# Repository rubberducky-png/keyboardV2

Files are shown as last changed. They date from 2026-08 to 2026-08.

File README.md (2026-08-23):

# keyboardV2: compact 61-key keyboard

A fully custom 61-key mechanical keyboard designed by me, including the PCB, case, firmware, and assembly.

Funded With The Macondo Program

## Features

- Custom PCB designed from scratch
- Hot-swappable MX-compatible switches
- VIA firmware
- Screw-in stabilizers
- 3D printed two-piece tray mount case
- Switch plate
- PCB foam
- bluetooth
- RGB lights
  
## Why I Built It

I built another keyboard before this and ended up hating how it looked and how I desgined it. So I went back to the drawing board and decided to make one I would actually like.

## Design Process

The project began by selecting a 61-key layout that has a lot of function but is also on the smaller side. I then designed the PCB in KiCad, routed all the traces, and added support for hot-swap sockets and USB-C connectivity. After the electronics were complete I designed a simple tray mount in Onshape. The case is made out of two PLA printed pieces and includes a shelf for the pcb to rest on. Because of small bed size I will have to print them in pieces.

Finally, the keyboard will be flashed with VIA firmware

## Challenges

Some of the biggest challenges included:

- Learning PCB routing and keyboard matrix design
- Designing a printable case that was able to support the pcb well
- Ensuring all mounting points aligned correctly

## Images and Renders!

### Matrix Schematic


### OnShape Render

#### Case


### PCB


### Assembly


## Bill of Materials (BOM)

| # | Component | Qty. | Cost |
|---:|---|---:|---:|
| 1 | Glorious Fox Linear Mechanical Switches | 110 | $24.99 |
| 2 | 1N4148 Diodes | 120 | $5.99 |
| 3 | GATERON PCB Mounted Stabilizer | 1 | $9.10 |
| 4 | SuperMini nRF52840 | 1 | $13.99 |
| 5 | SK6812MINI-E | 100 | $18 |
| 6 | Kalih Hotswap sockets | 100 | $12.50 |
| 7 | JLCPCB PCB Fabrication + shipping | 5 | $24.14 |
| 8 | 3.7V LiPo cell rated ~750mAh | 1 | $8.49 |
| 9 | JST-PH, 2mm pitch connector | 1 | $5.99 |
| 10 | standard SPDT slide switch, 0.1" (2.54mm) pin spacing | 1 | $7.99 |
| 11 | 2 Pin Momentary Tactile Tact Push Button | 1 | $5.99 |
| 12 | Womier Double Shot PBT Keycaps Set Cherry Profile | 1 | $17.99 |
| 13 | 100nF capacitors | 1 | $4.99 |
| 13 | Chip Capacitor MLCC 22uF | 1 | $7.60 |
| | **Total** | | **$167.75** |

## Shoutout hackclub and the macondo program

</center>

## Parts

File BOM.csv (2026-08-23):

SI No. | Name | Notes | Quantity | Price Per Unit | Cost | Total | Link
1 | Glorious Fox Linear Mechanical Switches | MX-compatible linear switches; 110-pack | 110 | 0.2272 | 24.99 |  | https://www.amazon.com/GLORIOUS-Linear-Mechanical-Switches-Keyboards/dp/B0D7QW8SQ9
2 | 1N4148 Diodes | Through-hole switching diodes for keyboard matrix | 120 | 0.0499 | 5.99 |  | https://www.amazon.com/120Pcs-Rectifier-100Volt-Electronic-Silicon/dp/B0DN62QFYS
3 | GATERON PCB Mounted Stabilizer | Set for stabilizing larger keys (spacebar, shift, enter) | 1 | 9.10 | 9.10 |  | https://www.gateron.com/products/gateron-pcb-mounted-stabilizer?VariantsId=10538
4 | SuperMini nRF52840 | Pro Micro alternative BLE dev board, ZMK/Nice!Nano compatible | 1 | 13.99 | 13.99 |  | https://www.amazon.com/AITRIP-Development-Bluetooth-Management-Module%EF%BC%8CNano/dp/B0DCZJKYL1
5 | SK6812MINI-E | Addressable per-key RGB LED, 100-pack | 100 | 0.18 | 18.00 |  | https://www.amazon.com/100PCS-Similar-WS2812B-Individually-Addressable/dp/B0DMNBBM9V
6 | Kailh Hotswap sockets | MX-compatible hotswap sockets, 100-pack | 100 | 0.125 | 12.50 |  | https://www.amazon.com/Hot-swappable-Socket-CPG151101S11-Mechanical-Keyboard/dp/B096WZ6TJ5
7 | JLCPCB PCB Fabrication + shipping | 5 PCBs; manufacturing + shipping from actual quote | 5 | 4.828 | 24.14 |  | https://jlcpcb.com
8 | 3.7V LiPo cell rated ~750mAh | Rechargeable lithium polymer cell w/ JST-PH connector | 1 | 8.49 | 8.49 |  | https://www.amazon.com/YTKavq-Battery-Lithium-Rechargeable-Connector/dp/B08TV4J9H7
9 | JST-PH, 2mm pitch connector | Battery connector; female socket w/ silicone cable | 1 | 5.99 | 5.99 |  | https://www.amazon.com/JST-PH-Connector-Silicone-Cables-Female/dp/B0F9PD2LPW
10 | standard SPDT slide switch, 0.1" (2.54mm) pin spacing | On/off power switch | 1 | 7.99 | 7.99 |  | https://www.amazon.com/SPDT-Mini-Micro-Slide-Switch/dp/B0DN69PJ43
11 | 2 Pin Momentary Tactile Tact Push Button | Reset button | 1 | 5.99 | 5.99 |  | https://www.amazon.com/Momentary-Tactile-Switches-Through-Breadboard/dp/B0G5Q9RPJW
12 | Womier Double Shot PBT Keycaps Set Cherry Profile | Doubleshot PBT keycap set, Cherry profile | 1 | 17.99 | 17.99 |  | https://www.amazon.com/Keycaps-Doubleshot-Percent-Mechanical-Keyboard/dp/B0DDC6PNY6
13 | 22uF 0805 MLCC (CS2012X5R226M250NRE) | Bulk capacitor for LED power line, 0805 SMD, 10-pack | 10 | 0.499 | 4.99 |  | https://www.amazon.com/Chip-Capacitor-MLCC-22uF-CS2012X5R226M250NRE/dp/B096WDCLWY
14 | CHANZON 100nF 0805 SMD Ceramic Capacitor | Decoupling cap, one per LED (61 needed), 100-pack | 100 | 0.076 | 7.60 |  | https://www.amazon.com/CHANZON-100nF-Ceramic-Capacitor-100pcs/dp/B0GWH4RRQS
 |  |  |  |  |  | 167.75

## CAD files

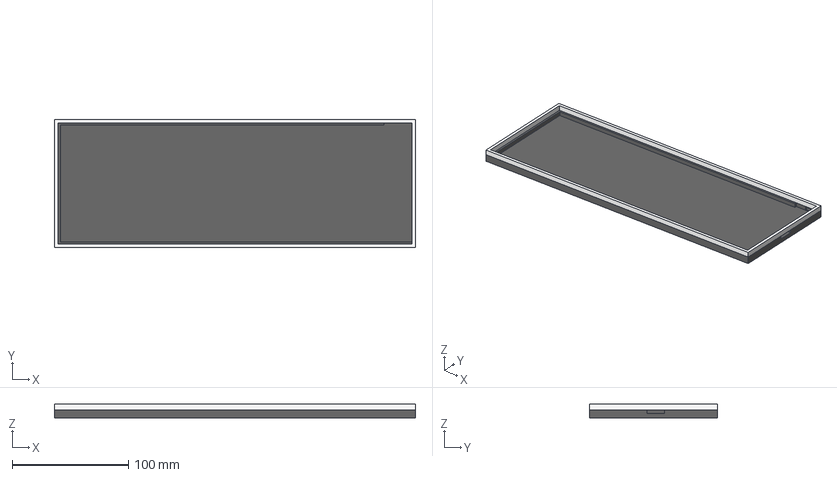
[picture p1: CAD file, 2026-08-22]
CAD/Case.step
310.7 x 110.5 x 12.0 mm

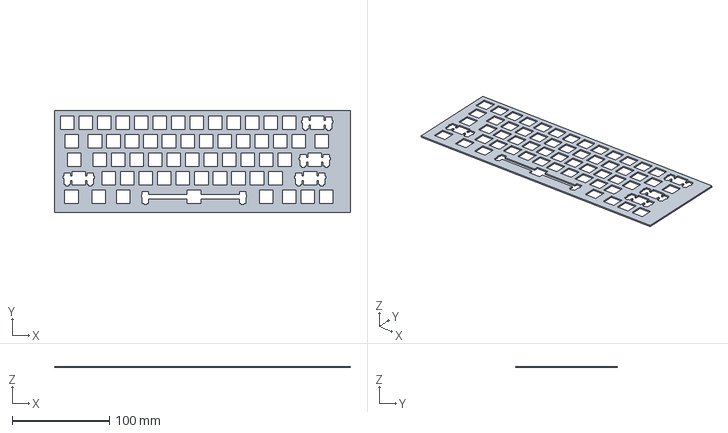
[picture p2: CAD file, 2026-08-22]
CAD/Plate.step
304.5 x 105.1 x 1.50 mm

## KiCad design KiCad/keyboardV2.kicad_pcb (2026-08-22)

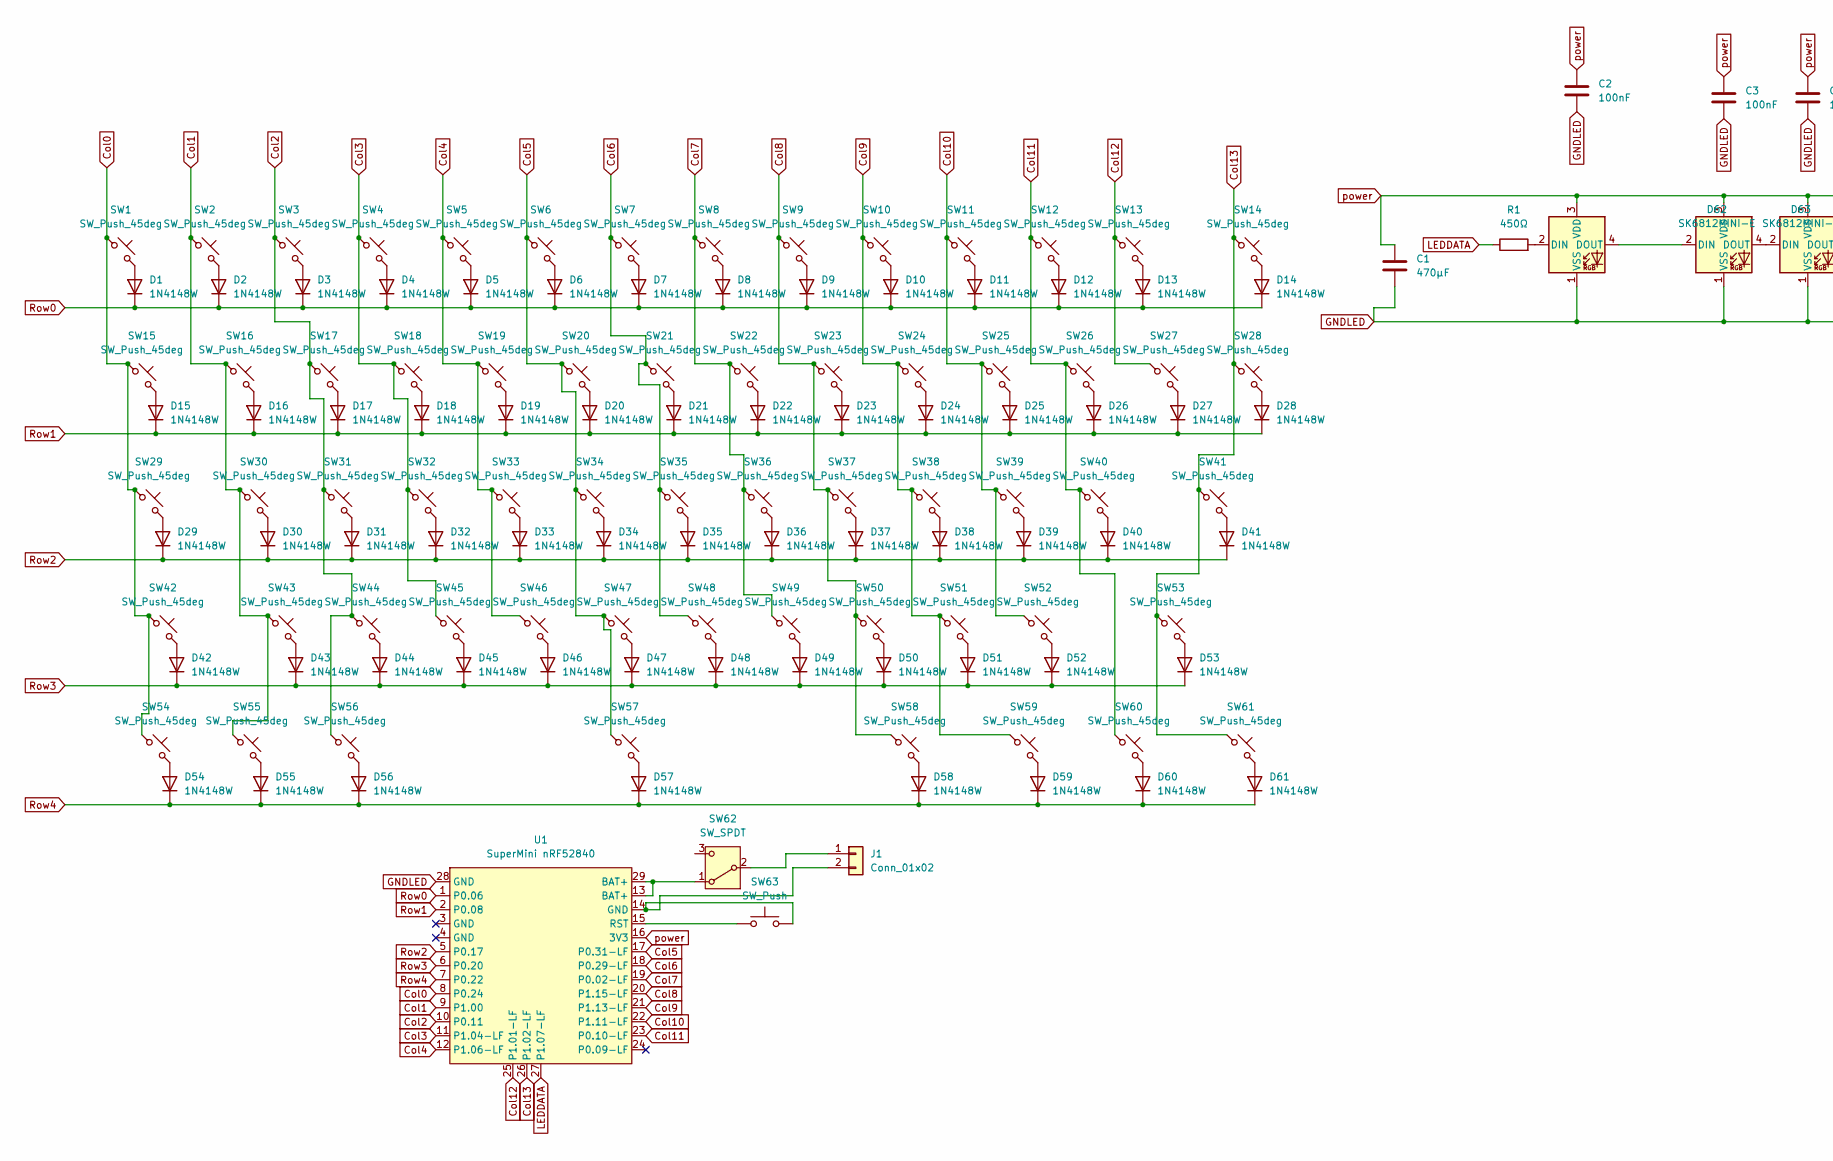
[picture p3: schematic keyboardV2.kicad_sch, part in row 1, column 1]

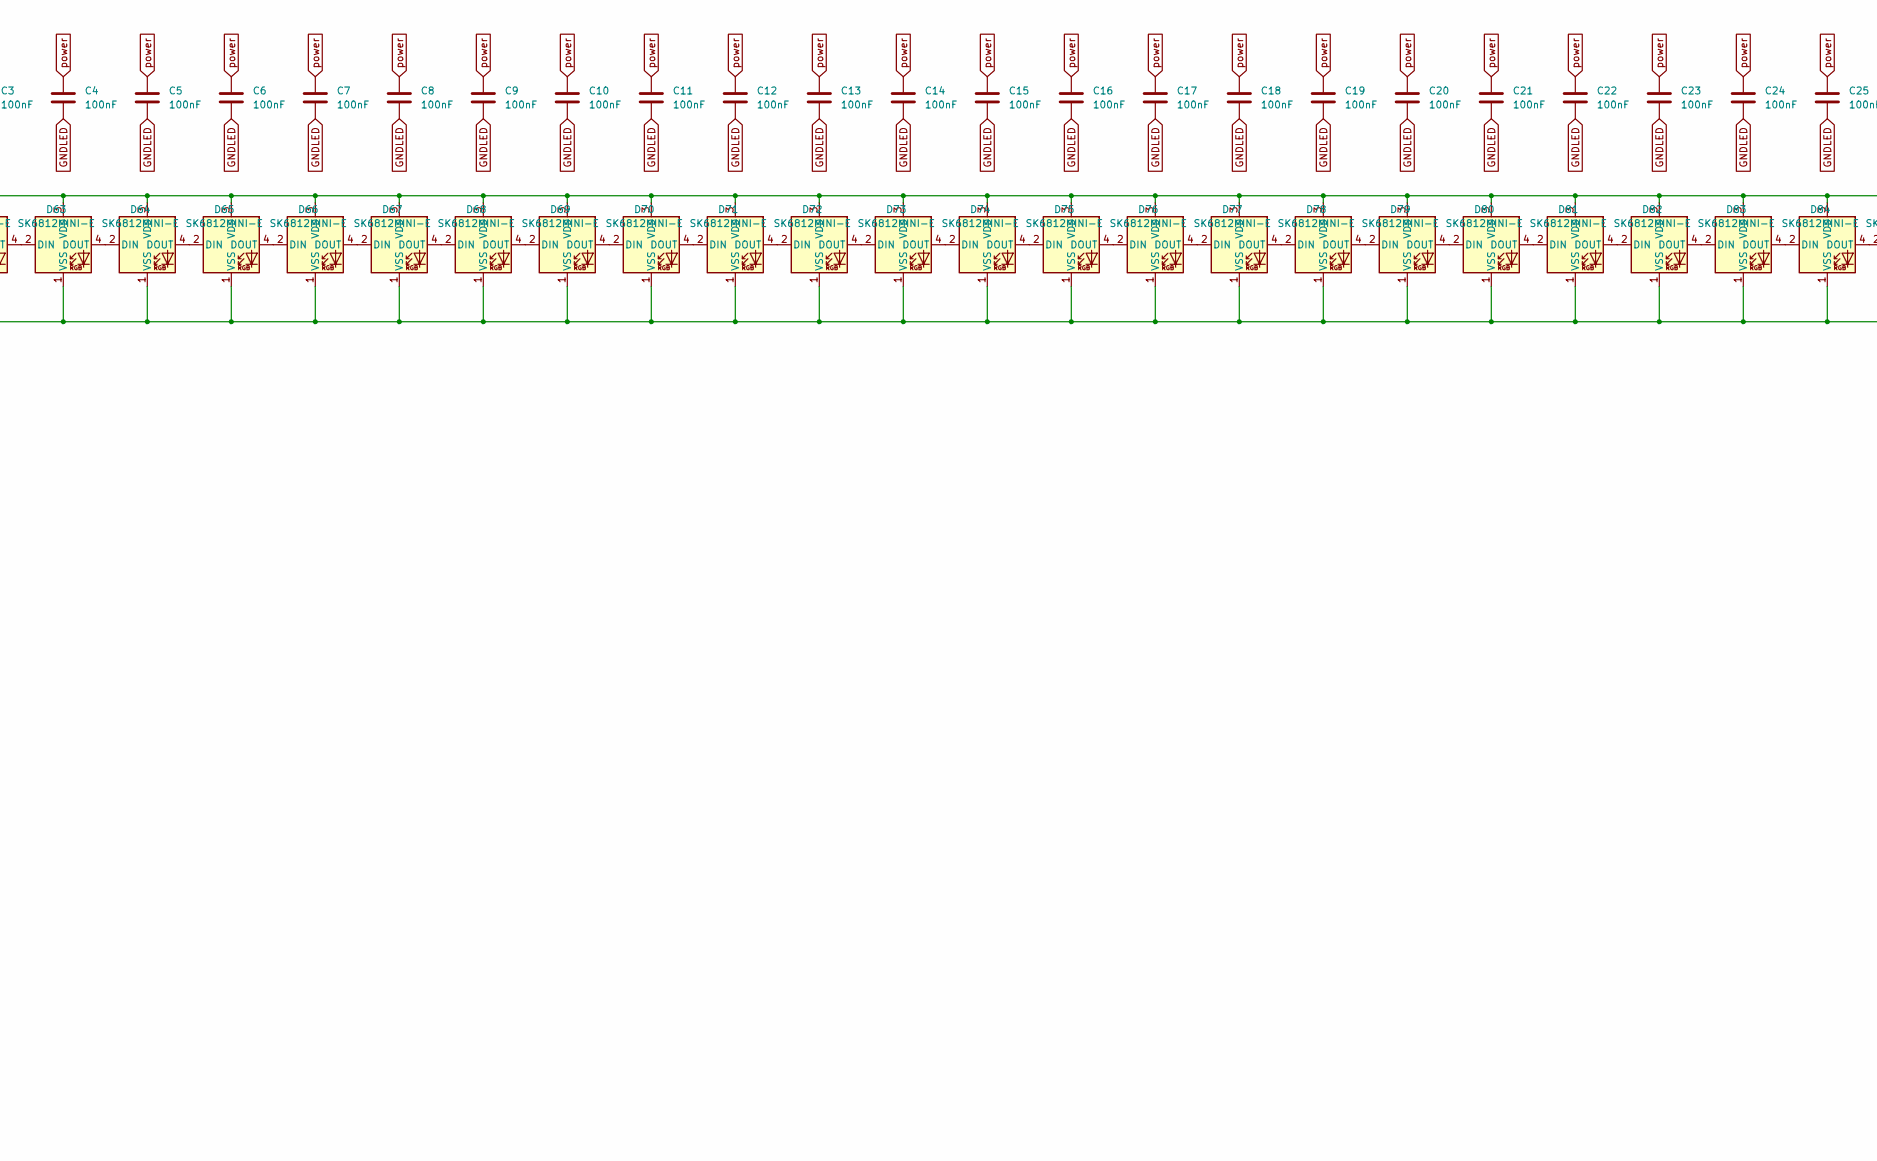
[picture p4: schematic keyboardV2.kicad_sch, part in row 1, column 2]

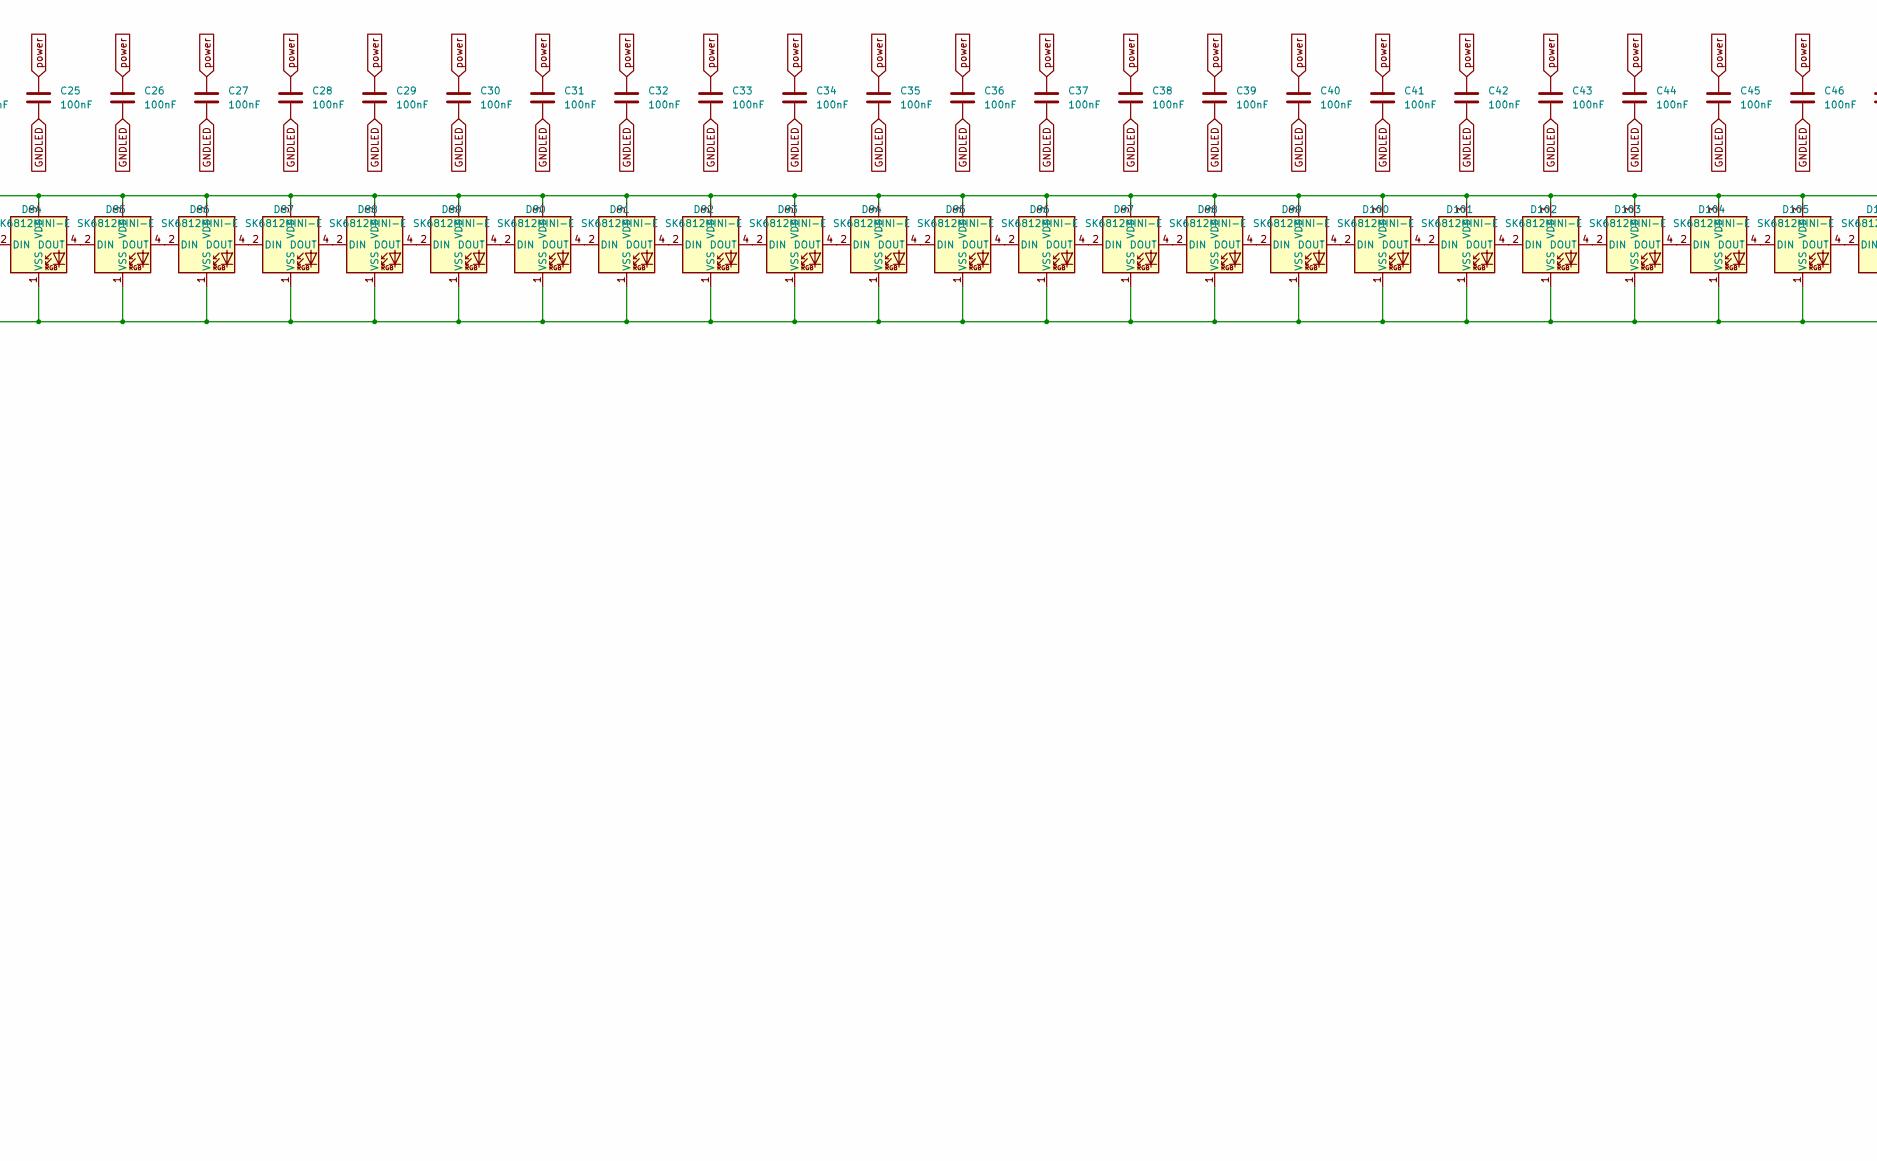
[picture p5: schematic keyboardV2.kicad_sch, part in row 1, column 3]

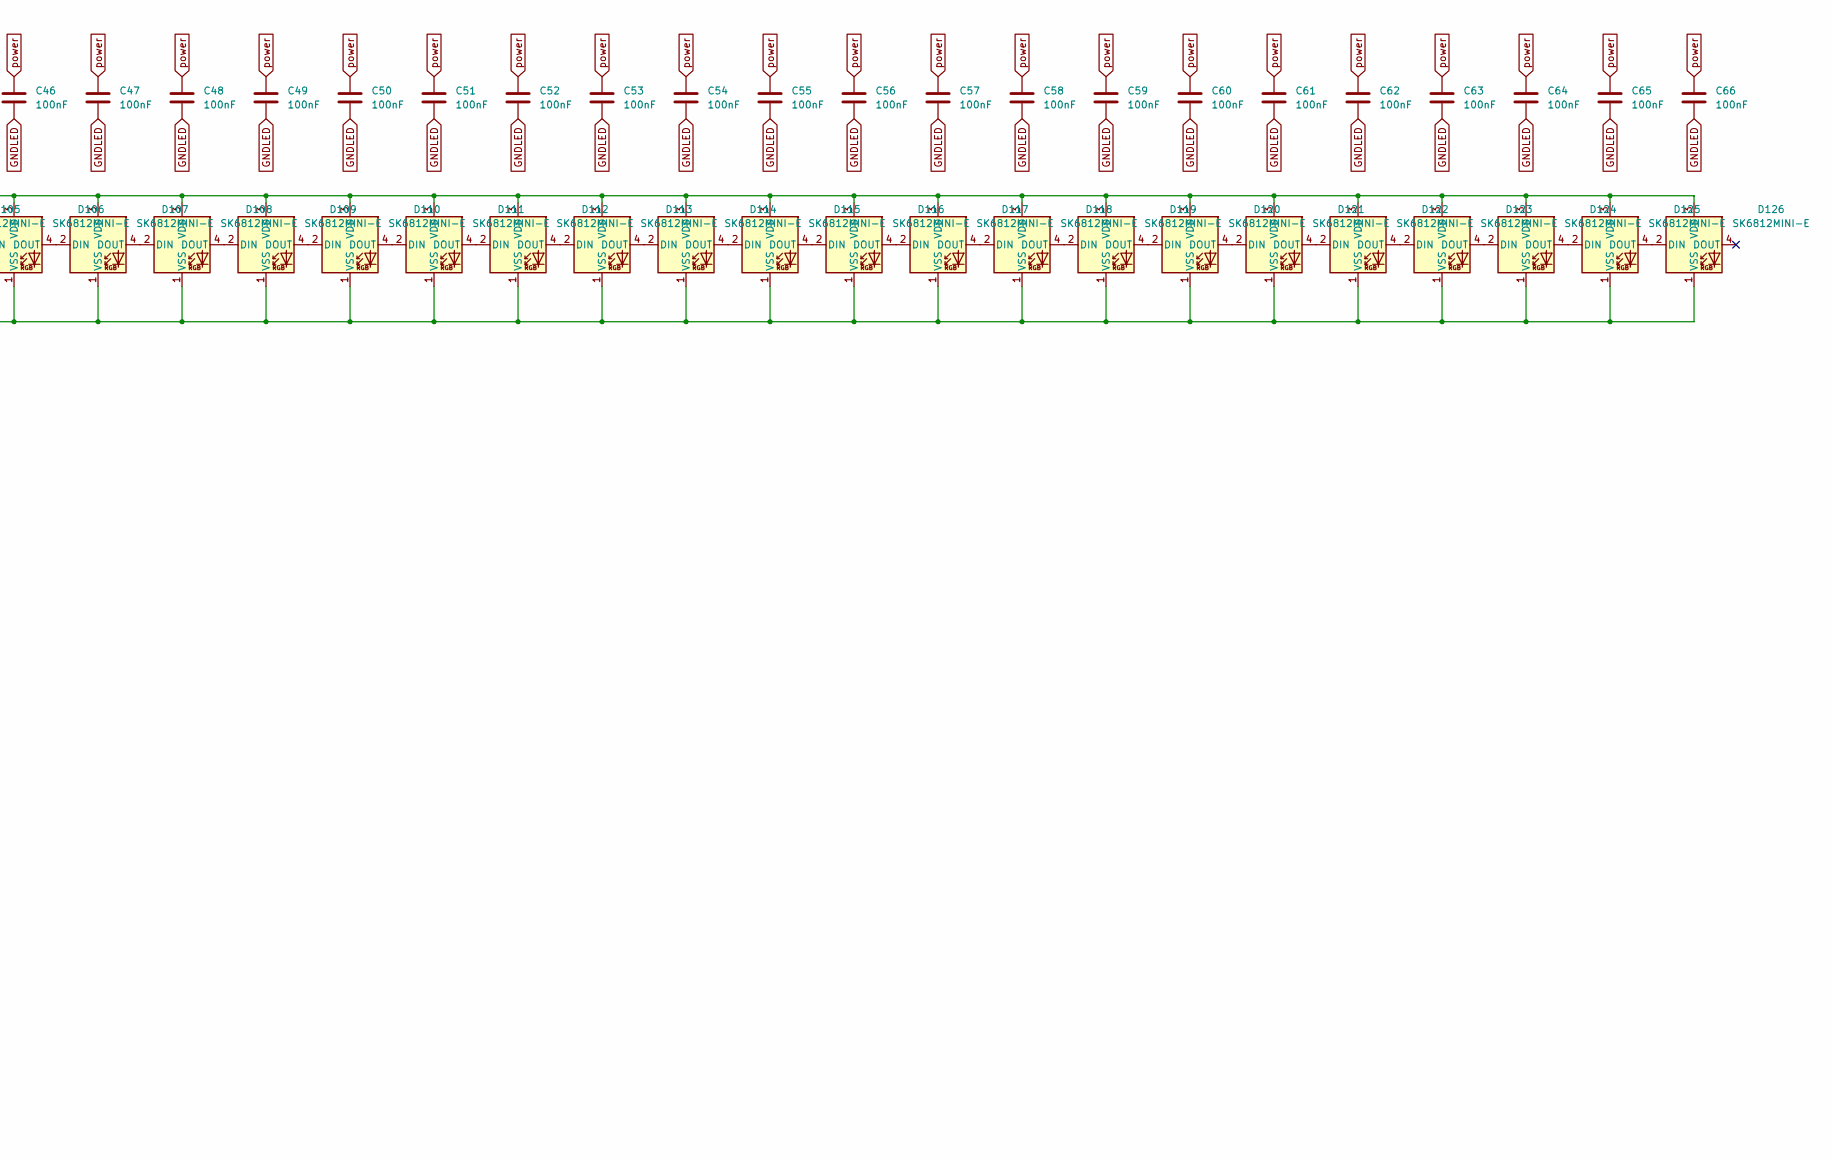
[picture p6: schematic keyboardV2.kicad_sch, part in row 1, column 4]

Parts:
C1: 470µF; C_0805_2012Metric
C2, C3, C4, C5, C6, C7, C8, C9, C10, C11, C12, C13, C14, C15, C16, C17, C18, C19, C20, C21, C22, C23, C24, C25, C26, C27, C28, C29, C30, C31, C32, C33, C34, C35, C36, C37, C38, C39, C40, C41, C42, C43, C44, C45, C46, C47, C48, C49, C50, C51, C52, C53, C54, C55, C56, C57, C58, C59, C60, C61, C62, C63, C64, C65, C66: 100nF; C_0805_2012Metric
D1, D2, D3, D4, D5, D6, D7, D8, D9, D10, D11, D12, D13, D14, D15, D16, D17, D18, D19, D20, D21, D22, D23, D24, D25, D26, D27, D28, D29, D30, D31, D32, D33, D34, D35, D36, D37, D38, D39, D40, D41, D42, D43, D44, D45, D46, D47, D48, D49, D50, D51, D52, D53, D54, D55, D56, D57, D58, D59, D60, D61: 1N4148W; D_SOD-123
D62, D63, D64, D65, D66, D67, D68, D69, D70, D71, D72, D73, D74, D75, D76, D77, D78, D79, D80, D81, D82, D83, D84, D85, D86, D87, D88, D89, D90, D91, D92, D93, D94, D95, D96, D97, D98, D99, D100, D101, D102, D103, D104, D105, D106, D107, D108, D109, D110, D111, D112, D113, D114, D115, D116, D117, D118, D119, D120, D121, D122, D123, D124, D125, D126: SK6812MINI-E; LED_SK6812MINI-E_3.2x2.8mm_P1.5mm_ReverseMount
J1: Conn_01x02; JST_PH_S2B-PH-K_1x02_P2.00mm_Horizontal
R1: 450Ω; R_0805_2012Metric
SW1, SW2, SW3, SW4, SW5, SW6, SW7, SW8, SW9, SW10, SW11, SW12, SW13, SW16, SW17, SW18, SW19, SW20, SW21, SW22, SW23, SW24, SW25, SW26, SW27, SW30, SW31, SW32, SW33, SW34, SW35, SW36, SW37, SW38, SW39, SW40, SW43, SW44, SW45, SW46, SW47, SW48, SW49, SW50, SW51, SW52, SW59, SW60, SW61: SW_Push_45deg; MX-Hotswap-1U
SW14: SW_Push_45deg; MX-Hotswap-2U
SW15, SW28, SW54, SW58: SW_Push_45deg; MX-Hotswap-1.5U
SW29: SW_Push_45deg; MX-Hotswap-1.75U
SW41, SW42: SW_Push_45deg; MX-Hotswap-2.25U
SW53: SW_Push_45deg; MX-Hotswap-2.75U
SW55, SW56: SW_Push_45deg; MX-Hotswap-1.25U
SW57: SW_Push_45deg; MX-Hotswap-6.25U
SW62: SW_SPDT; SW_SPDT_CK_JS102011SAQN
SW63: SW_Push; SW_SPST_B3U-3100P-B
U1: SuperMini nRF52840; SuperMini NRF52840

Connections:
Col0: SW1.1, SW15.1, SW29.1, SW42.1, SW54.1, U1.8 (P0.24)
Col1: SW2.1, SW16.1, SW30.1, SW43.1, SW55.1, U1.9 (P1.00)
Col2: SW3.1, SW17.1, SW31.1, SW44.1, SW56.1, U1.10 (P0.11)
Col3: SW4.1, SW18.1, SW32.1, SW45.1, U1.11 (P1.04-LF)
Col4: SW5.1, SW19.1, SW33.1, SW46.1, U1.12 (P1.06-LF)
Col5: SW6.1, SW20.1, SW34.1, SW47.1, SW57.1, U1.17 (P0.31-LF)
Col6: SW7.1, SW21.1, SW35.1, SW48.1, U1.18 (P0.29-LF)
Col7: SW8.1, SW22.1, SW36.1, SW49.1, U1.19 (P0.02-LF)
Col8: SW9.1, SW23.1, SW37.1, SW50.1, SW58.1, U1.20 (P1.15-LF)
Col9: SW10.1, SW24.1, SW38.1, SW51.1, SW59.1, U1.21 (P1.13-LF)
Col10: SW11.1, SW25.1, SW39.1, SW52.1, U1.22 (P1.11-LF)
Col11: SW12.1, SW26.1, SW40.1, SW60.1, U1.23 (P0.10-LF)
Col12: SW13.1, SW27.1, U1.25 (P1.01-LF)
Col13: SW14.1, SW28.1, SW41.1, SW53.1, SW61.1, U1.26 (P1.02-LF)
GNDLED: C1.1, C2.1, C3.1, C4.1, C5.1, C6.1, C7.1, C8.1, C9.1, C10.1, C11.1, C12.1, C13.1, C14.1, C15.1, C16.1, C17.1, C18.1, C19.1, C20.1, C21.1, C22.1, C23.1, C24.1, C25.1, C26.1, C27.1, C28.1, C29.1, C30.1, C31.1, C32.1, C33.1, C34.1, C35.1, C36.1, C37.1, C38.1, C39.1, C40.1, C41.1, C42.1, C43.1, C44.1, C45.1, C46.1, C47.1, C48.1, C49.1, C50.1, C51.1, C52.1, C53.1, C54.1, C55.1, C56.1, C57.1, C58.1, C59.1, C60.1, C61.1, C62.1, C63.1, C64.1, C65.1, C66.1, D62.1 (VSS), D63.1 (VSS), D64.1 (VSS), D65.1 (VSS), D66.1 (VSS), D67.1 (VSS), D68.1 (VSS), D69.1 (VSS), D70.1 (VSS), D71.1 (VSS), D72.1 (VSS), D73.1 (VSS), D74.1 (VSS), D75.1 (VSS), D76.1 (VSS), D77.1 (VSS), D78.1 (VSS), D79.1 (VSS), D80.1 (VSS), D81.1 (VSS), D82.1 (VSS), D83.1 (VSS), D84.1 (VSS), D85.1 (VSS), D86.1 (VSS), D87.1 (VSS), D88.1 (VSS), D89.1 (VSS), D90.1 (VSS), D91.1 (VSS), D92.1 (VSS), D93.1 (VSS), D94.1 (VSS), D95.1 (VSS), D96.1 (VSS), D97.1 (VSS), D98.1 (VSS), D99.1 (VSS), D100.1 (VSS), D101.1 (VSS), D102.1 (VSS), D103.1 (VSS), D104.1 (VSS), D105.1 (VSS), D106.1 (VSS), D107.1 (VSS), D108.1 (VSS), D109.1 (VSS), D110.1 (VSS), D111.1 (VSS), D112.1 (VSS), D113.1 (VSS), D114.1 (VSS), D115.1 (VSS), D116.1 (VSS), D117.1 (VSS), D118.1 (VSS), D119.1 (VSS), D120.1 (VSS), D121.1 (VSS), D122.1 (VSS), D123.1 (VSS), D124.1 (VSS), D125.1 (VSS), D126.1 (VSS), U1.28 (GND)
LEDDATA: R1.1, U1.27 (P1.07-LF)
unnamed: D1.2 (A), SW1.2
unnamed: D2.2 (A), SW2.2
unnamed: D3.2 (A), SW3.2
unnamed: D4.2 (A), SW4.2
unnamed: D5.2 (A), SW5.2
unnamed: D6.2 (A), SW6.2
unnamed: D7.2 (A), SW7.2
unnamed: D8.2 (A), SW8.2
unnamed: D9.2 (A), SW9.2
unnamed: D10.2 (A), SW10.2
unnamed: D11.2 (A), SW11.2
unnamed: D12.2 (A), SW12.2
unnamed: D13.2 (A), SW13.2
unnamed: D14.2 (A), SW14.2
unnamed: D15.2 (A), SW15.2
unnamed: D16.2 (A), SW16.2
unnamed: D17.2 (A), SW17.2
unnamed: D18.2 (A), SW18.2
unnamed: D19.2 (A), SW19.2
unnamed: D20.2 (A), SW20.2
unnamed: D21.2 (A), SW21.2
unnamed: D22.2 (A), SW22.2
unnamed: D23.2 (A), SW23.2
unnamed: D24.2 (A), SW24.2
unnamed: D25.2 (A), SW25.2
unnamed: D26.2 (A), SW26.2
unnamed: D27.2 (A), SW27.2
unnamed: D28.2 (A), SW28.2
unnamed: D29.2 (A), SW29.2
unnamed: D30.2 (A), SW30.2
unnamed: D31.2 (A), SW31.2
unnamed: D32.2 (A), SW32.2
unnamed: D33.2 (A), SW33.2
unnamed: D34.2 (A), SW34.2
unnamed: D35.2 (A), SW35.2
unnamed: D36.2 (A), SW36.2
unnamed: D37.2 (A), SW37.2
unnamed: D38.2 (A), SW38.2
unnamed: D39.2 (A), SW39.2
unnamed: D40.2 (A), SW40.2
unnamed: D41.2 (A), SW41.2
unnamed: D42.2 (A), SW42.2
unnamed: D43.2 (A), SW43.2
unnamed: D44.2 (A), SW44.2
unnamed: D45.2 (A), SW45.2
unnamed: D46.2 (A), SW46.2
unnamed: D47.2 (A), SW47.2
unnamed: D48.2 (A), SW48.2
unnamed: D49.2 (A), SW49.2
unnamed: D50.2 (A), SW50.2
unnamed: D51.2 (A), SW51.2
unnamed: D52.2 (A), SW52.2
unnamed: D53.2 (A), SW53.2
unnamed: D54.2 (A), SW54.2
unnamed: D55.2 (A), SW55.2
unnamed: D56.2 (A), SW56.2
unnamed: D57.2 (A), SW57.2
unnamed: D58.2 (A), SW58.2
unnamed: D59.2 (A), SW59.2
unnamed: D60.2 (A), SW60.2
unnamed: D61.2 (A), SW61.2
unnamed: D62.2 (DIN), R1.2
unnamed: D62.4 (DOUT), D63.2 (DIN)
unnamed: D63.4 (DOUT), D64.2 (DIN)
unnamed: D64.4 (DOUT), D65.2 (DIN)
unnamed: D65.4 (DOUT), D66.2 (DIN)
unnamed: D66.4 (DOUT), D67.2 (DIN)
unnamed: D67.4 (DOUT), D68.2 (DIN)
unnamed: D68.4 (DOUT), D69.2 (DIN)
unnamed: D69.4 (DOUT), D70.2 (DIN)
unnamed: D70.4 (DOUT), D71.2 (DIN)
unnamed: D71.4 (DOUT), D72.2 (DIN)
unnamed: D72.4 (DOUT), D73.2 (DIN)
unnamed: D73.4 (DOUT), D74.2 (DIN)
unnamed: D74.4 (DOUT), D75.2 (DIN)
unnamed: D75.4 (DOUT), D76.2 (DIN)
unnamed: D76.4 (DOUT), D77.2 (DIN)
unnamed: D77.4 (DOUT), D78.2 (DIN)
unnamed: D78.4 (DOUT), D79.2 (DIN)
unnamed: D79.4 (DOUT), D80.2 (DIN)
unnamed: D80.4 (DOUT), D81.2 (DIN)
unnamed: D81.4 (DOUT), D82.2 (DIN)
unnamed: D82.4 (DOUT), D83.2 (DIN)
unnamed: D83.4 (DOUT), D84.2 (DIN)
unnamed: D84.4 (DOUT), D85.2 (DIN)
unnamed: D85.4 (DOUT), D86.2 (DIN)
unnamed: D86.4 (DOUT), D87.2 (DIN)
unnamed: D87.4 (DOUT), D88.2 (DIN)
unnamed: D88.4 (DOUT), D89.2 (DIN)
unnamed: D89.4 (DOUT), D90.2 (DIN)
unnamed: D90.4 (DOUT), D91.2 (DIN)
unnamed: D91.4 (DOUT), D92.2 (DIN)
unnamed: D92.4 (DOUT), D93.2 (DIN)
unnamed: D93.4 (DOUT), D94.2 (DIN)
unnamed: D94.4 (DOUT), D95.2 (DIN)
unnamed: D95.4 (DOUT), D96.2 (DIN)
unnamed: D96.4 (DOUT), D97.2 (DIN)
unnamed: D97.4 (DOUT), D98.2 (DIN)
unnamed: D98.4 (DOUT), D99.2 (DIN)
unnamed: D99.4 (DOUT), D100.2 (DIN)
unnamed: D100.4 (DOUT), D101.2 (DIN)
unnamed: D101.4 (DOUT), D102.2 (DIN)
unnamed: D102.4 (DOUT), D103.2 (DIN)
unnamed: D103.4 (DOUT), D104.2 (DIN)
unnamed: D104.4 (DOUT), D105.2 (DIN)
unnamed: D105.4 (DOUT), D106.2 (DIN)
unnamed: D106.4 (DOUT), D107.2 (DIN)
unnamed: D107.4 (DOUT), D108.2 (DIN)
unnamed: D108.4 (DOUT), D109.2 (DIN)
unnamed: D109.4 (DOUT), D110.2 (DIN)
unnamed: D110.4 (DOUT), D111.2 (DIN)
unnamed: D111.4 (DOUT), D112.2 (DIN)
unnamed: D112.4 (DOUT), D113.2 (DIN)
unnamed: D113.4 (DOUT), D114.2 (DIN)
unnamed: D114.4 (DOUT), D115.2 (DIN)
unnamed: D115.4 (DOUT), D116.2 (DIN)
unnamed: D116.4 (DOUT), D117.2 (DIN)
unnamed: D117.4 (DOUT), D118.2 (DIN)
unnamed: D118.4 (DOUT), D119.2 (DIN)
unnamed: D119.4 (DOUT), D120.2 (DIN)
unnamed: D120.4 (DOUT), D121.2 (DIN)
unnamed: D121.4 (DOUT), D122.2 (DIN)
unnamed: D122.4 (DOUT), D123.2 (DIN)
unnamed: D123.4 (DOUT), D124.2 (DIN)
unnamed: D124.4 (DOUT), D125.2 (DIN)
unnamed: D125.4 (DOUT), D126.2 (DIN)
unnamed: J1.1, SW62.2 (B)
unnamed: J1.2, SW63.2, U1.14 (GND)
unnamed: SW62.1 (A), U1.13 (BAT+), U1.29 (BAT+)
unnamed: SW63.1, U1.15 (RST)
Row0: D1.1 (K), D2.1 (K), D3.1 (K), D4.1 (K), D5.1 (K), D6.1 (K), D7.1 (K), D8.1 (K), D9.1 (K), D10.1 (K), D11.1 (K), D12.1 (K), D13.1 (K), D14.1 (K), U1.1 (P0.06)
Row1: D15.1 (K), D16.1 (K), D17.1 (K), D18.1 (K), D19.1 (K), D20.1 (K), D21.1 (K), D22.1 (K), D23.1 (K), D24.1 (K), D25.1 (K), D26.1 (K), D27.1 (K), D28.1 (K), U1.2 (P0.08)
Row2: D29.1 (K), D30.1 (K), D31.1 (K), D32.1 (K), D33.1 (K), D34.1 (K), D35.1 (K), D36.1 (K), D37.1 (K), D38.1 (K), D39.1 (K), D40.1 (K), D41.1 (K), U1.5 (P0.17)
Row3: D42.1 (K), D43.1 (K), D44.1 (K), D45.1 (K), D46.1 (K), D47.1 (K), D48.1 (K), D49.1 (K), D50.1 (K), D51.1 (K), D52.1 (K), D53.1 (K), U1.6 (P0.20)
Row4: D54.1 (K), D55.1 (K), D56.1 (K), D57.1 (K), D58.1 (K), D59.1 (K), D60.1 (K), D61.1 (K), U1.7 (P0.22)
power: C1.2, C2.2, C3.2, C4.2, C5.2, C6.2, C7.2, C8.2, C9.2, C10.2, C11.2, C12.2, C13.2, C14.2, C15.2, C16.2, C17.2, C18.2, C19.2, C20.2, C21.2, C22.2, C23.2, C24.2, C25.2, C26.2, C27.2, C28.2, C29.2, C30.2, C31.2, C32.2, C33.2, C34.2, C35.2, C36.2, C37.2, C38.2, C39.2, C40.2, C41.2, C42.2, C43.2, C44.2, C45.2, C46.2, C47.2, C48.2, C49.2, C50.2, C51.2, C52.2, C53.2, C54.2, C55.2, C56.2, C57.2, C58.2, C59.2, C60.2, C61.2, C62.2, C63.2, C64.2, C65.2, C66.2, D62.3 (VDD), D63.3 (VDD), D64.3 (VDD), D65.3 (VDD), D66.3 (VDD), D67.3 (VDD), D68.3 (VDD), D69.3 (VDD), D70.3 (VDD), D71.3 (VDD), D72.3 (VDD), D73.3 (VDD), D74.3 (VDD), D75.3 (VDD), D76.3 (VDD), D77.3 (VDD), D78.3 (VDD), D79.3 (VDD), D80.3 (VDD), D81.3 (VDD), D82.3 (VDD), D83.3 (VDD), D84.3 (VDD), D85.3 (VDD), D86.3 (VDD), D87.3 (VDD), D88.3 (VDD), D89.3 (VDD), D90.3 (VDD), D91.3 (VDD), D92.3 (VDD), D93.3 (VDD), D94.3 (VDD), D95.3 (VDD), D96.3 (VDD), D97.3 (VDD), D98.3 (VDD), D99.3 (VDD), D100.3 (VDD), D101.3 (VDD), D102.3 (VDD), D103.3 (VDD), D104.3 (VDD), D105.3 (VDD), D106.3 (VDD), D107.3 (VDD), D108.3 (VDD), D109.3 (VDD), D110.3 (VDD), D111.3 (VDD), D112.3 (VDD), D113.3 (VDD), D114.3 (VDD), D115.3 (VDD), D116.3 (VDD), D117.3 (VDD), D118.3 (VDD), D119.3 (VDD), D120.3 (VDD), D121.3 (VDD), D122.3 (VDD), D123.3 (VDD), D124.3 (VDD), D125.3 (VDD), D126.3 (VDD), U1.16 (3V3)

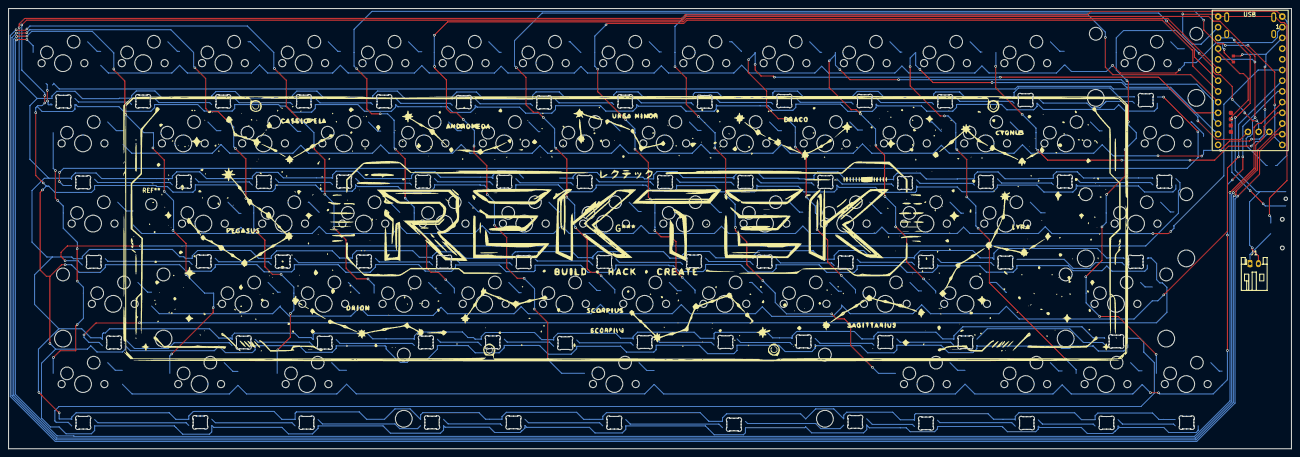
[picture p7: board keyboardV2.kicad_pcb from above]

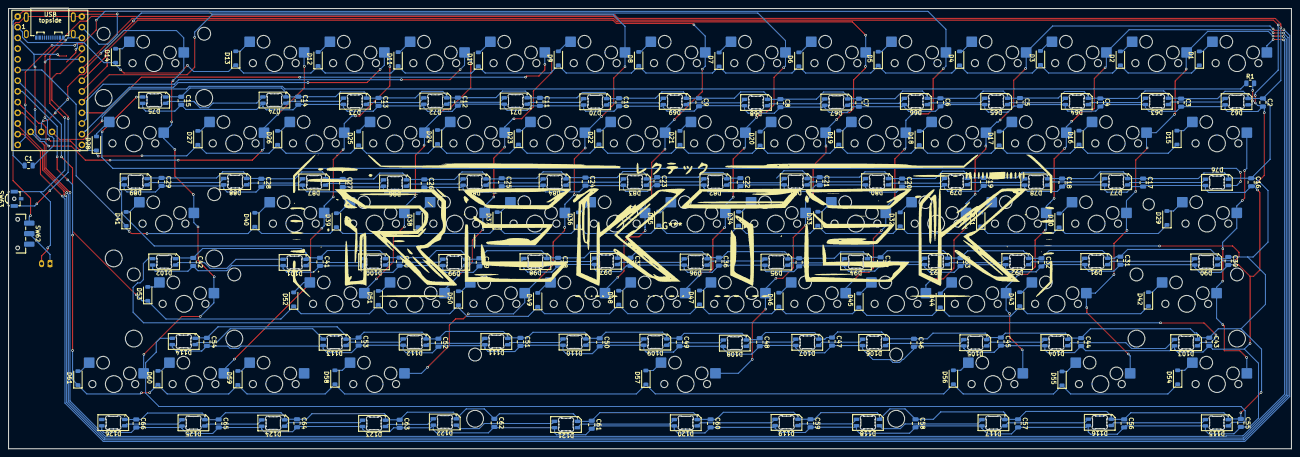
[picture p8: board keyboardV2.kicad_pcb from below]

Board: 2 copper layers, 304.6 x 104.5 mm, 258 parts (257 on the bottom side), 152 nets.

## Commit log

2026-08-21 Update BOM with new components and costs
2026-08-23 Correct spelling of 'Kalih' to 'Kailh' in BOM
    [BOM.csv]
2026-11-09 Revise component details in BOM.csv
    Updated quantities and prices for several components in the BOM. Adjusted total cost accordingly.
2026-11-09 Revise BOM with detailed components and cost summary
    Updated the Bill of Materials (BOM) section with detailed component descriptions, quantities, unit prices, and a cost summary for the custom 60% wireless mechanical keyboard.
2026-11-09 Update README with OnShape assembly file link
    Added link to public assembly file on OnShape.
2026-11-10 Add HiLetgo SMD Resistors Kit to BOM
2026-11-10 Remove price for HiLetgo SMD Resistors Kit
    Removed price for HiLetgo SMD Resistors Kit and adjusted CSV structure.
2026-11-10 Remove price for HiLetgo SMD Resistors Kit
    Removed the price from the HiLetgo 0805 SMD Resistors Kit entry in BOM.csv.
